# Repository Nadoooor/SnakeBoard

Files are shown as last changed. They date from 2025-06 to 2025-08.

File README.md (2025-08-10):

# SnakeBoard
It is a custom keycool84 size keyboard with dual oled screens and a rotary encoder.<br>
I made this project to improve my cad skills and pcb designing skills. Also, i need a good keyboard to write my homework with.<br>
The Onshape Doc: [DOC](https://cad.onshape.com/documents/902611e8b9feae564de8d9eb/w/ee044899b2f02c71afc87682/e/73f01ff6e236a97137583ab3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)<br>

## Photos:
### Schematic:


### PCB:


### 3D PCB:


### Final Case:


## BOM for SnakeBoard:
| Part name | link | price  |
|---|---|---|
| Key Switches x4 packs | [Link](https://www.amazon.eg/-/en/gp/product/B09QGQVQYD/ref=ox_sc_act_title_2?smid=A1ZVRGNO5AYLOV&psc=1) | $43.83 |
| keycaps | [Link](https://www.amazon.eg/-/en/Redragon-A101-Double-Shot-mechanical-keyboard/dp/B019OAQ6VI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) | $7.72  |
| Zener Diode BZX79-C5V1 (6.2 Volt) | [Link](https://mostelectronic.com/shop/components/diodes/zener-diode-bzx79-c5v1-6-2-volt/) | $0.92  |
| Solder Wire Singapore 25g (0.6mm -70/30) Singapore | [Link](https://mostelectronic.com/shop/tools/soldering-desoldering/solder-wire-singapore-25g-0-6mm-70-30-singapore/) | $1.53  |
| OLED LCD LED Display Module White (128X64) 0.96 inch) | [Link](https://mostelectronic.com/shop/displays-lcd-7-seg-led/lcd-modules-displays-lcd-7-seg-led/0-96%e2%80%b3-oled-4pin-lcd-led-display-module-i2c-iic-communicate-white-12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) | $6.25  |
| Rotary encoder | [Link](https://mostelectronic.com/shop/sensors/ec11-rotary-encoder-with-push-button-switch-5pin-15mm/) | $0.5  |
| Raspberry pi pico | [Link](https://mostelectronic.com/shop/arduino-development-boards/raspberry-pi/raspberry-pi-pico/) | $10 |
| Shift register |[Link](https://www.ram-e-shop.com/shop/74hc165-ic-74165-8-bit-parallel-in-serial-out-shift-register-6231) | $0.31  |
| Total JLCPCb with shipping|  | $30 |
| shipping for most electronics | | $3.06  |
| shipping for amazon eg | | $2 |
| 3D Printed case | | $36.10 |
| Total | | $141.59|

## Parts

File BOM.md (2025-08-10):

# BOM for SnakeBoard:
| Part name | link | price  |
|---|---|---|
| Key Switches x4 packs | [Link](https://www.amazon.eg/-/en/gp/product/B09QGQVQYD/ref=ox_sc_act_title_2?smid=A1ZVRGNO5AYLOV&psc=1) | $43.83 |
| keycaps | [Link](https://www.amazon.eg/-/en/Redragon-A101-Double-Shot-mechanical-keyboard/dp/B019OAQ6VI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) | $7.72  |
| Zener Diode BZX79-C5V1 (6.2 Volt) | [Link](https://mostelectronic.com/shop/components/diodes/zener-diode-bzx79-c5v1-6-2-volt/) | $0.92  |
| Solder Wire Singapore 25g (0.6mm -70/30) Singapore | [Link](https://mostelectronic.com/shop/tools/soldering-desoldering/solder-wire-singapore-25g-0-6mm-70-30-singapore/) | $1.53  |
| OLED LCD LED Display Module White (128X64) 0.96 inch) | [Link](https://mostelectronic.com/shop/displays-lcd-7-seg-led/lcd-modules-displays-lcd-7-seg-led/0-96%e2%80%b3-oled-4pin-lcd-led-display-module-i2c-iic-communicate-white-12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) | $6.25  |
| Rotary encoder | [Link](https://mostelectronic.com/shop/sensors/ec11-rotary-encoder-with-push-button-switch-5pin-15mm/) | $0.5  |
| Raspberry pi pico | [Link](https://mostelectronic.com/shop/arduino-development-boards/raspberry-pi/raspberry-pi-pico/) | $10 |
| Shift register |[Link](https://www.ram-e-shop.com/shop/74hc165-ic-74165-8-bit-parallel-in-serial-out-shift-register-6231) | $0.31  |
| Total JLCPCb with shipping|  | $30 |
| shipping for most electronics | | $3.06  |
| shipping for amazon eg | | $2 |
| 3D Printed case | | $36.10 |
| Total | | $141.59|

## Note:
JLCPCB total is with 20$ coupon:<br>

<br>
### Print legion shipping will be more then what i will pay for printing it in my country.

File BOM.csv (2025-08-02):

Part name | link | price
Key Switches x4 packs | https://www.amazon.eg/-/en/gp/product/B09QGQVQYD/ref=ox_sc_act_title_2?smid=A1ZVRGNO5AYLOV&psc=1 | $43.83
keycaps | https://www.amazon.eg/-/en/Redragon-A101-Double-Shot-mechanical-keyboard/dp/B019OAQ6VI | $7.72
Zener Diode BZX79-C5V1 (6.2 Volt) | https://mostelectronic.com/shop/components/diodes/zener-diode-bzx79-c5v1-6-2-volt/ | $0.92
Solder Wire Singapore 25g (0.6mm -70/30) Singapore | https://mostelectronic.com/shop/tools/soldering-desoldering/solder-wire-singapore-25g-0-6mm-70-30-singapore/ | $1.53
Soldering Iron Station Tips 5pcs | https://mostelectronic.com/shop/tools/soldering-desoldering/soldering-iron-station-tips-5pcs/ | $1.32
Joker Soldering Paste Flux for Multi-Purpose 50g | https://mostelectronic.com/shop/tools/soldering-desoldering/joker-soldering-paste-flux-for-multi-purpose-50g/ | $1.22
OLED LCD LED Display Module White (128X64) 0.96 inch) | https://mostelectronic.com/shop/displays-lcd-7-seg-led/lcd-modules-displays-lcd-7-seg-led/0-96%e2%80%b3-oled-4pin-lcd-led-display-module-i2c-iic-communicate-w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 | $6.25
Rotary encoder | https://mostelectronic.com/shop/sensors/ec11-rotary-encoder-with-push-button-switch-5pin-15mm/ | $0.5
Raspberry pi pico | https://mostelectronic.com/shop/arduino-development-boards/raspberry-pi/raspberry-pi-pico/ | $10
Shift register | https://www.ram-e-shop.com/shop/74hc165-ic-74165-8-bit-parallel-in-serial-out-shift-register-6231 | $0.31
Stablizers | https://ar.aliexpress.com/item/1005006010710197.html?mp=1 | $4
Total JLCPCb with shipping |  | $30
shipping for most electronics |  | $3.06
shipping for amazon eg |  | $2
3D Printed case |  | $36.10
Total |  | $148.1

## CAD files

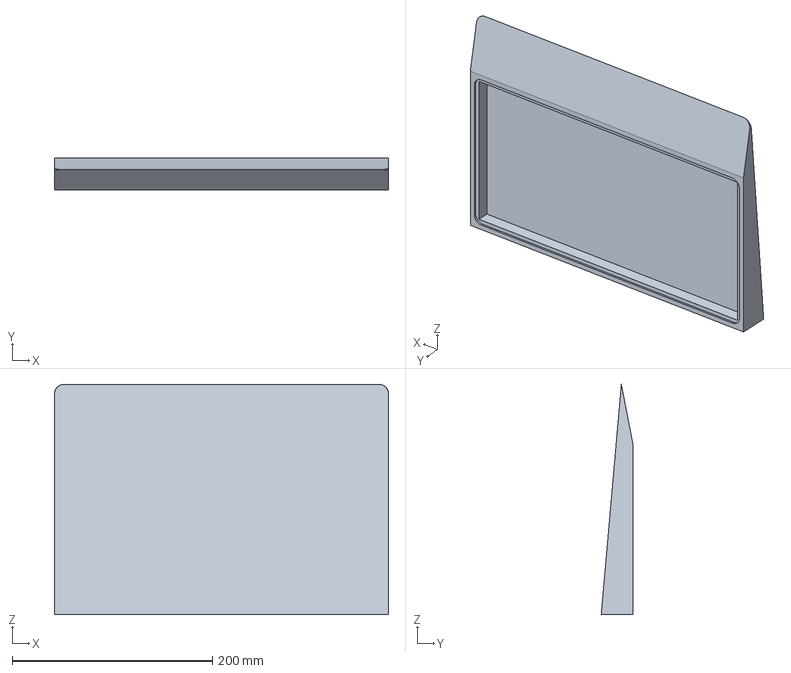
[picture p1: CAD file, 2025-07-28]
Production/Case/bottom.step
333.9 x 31.6 x 230.3 mm

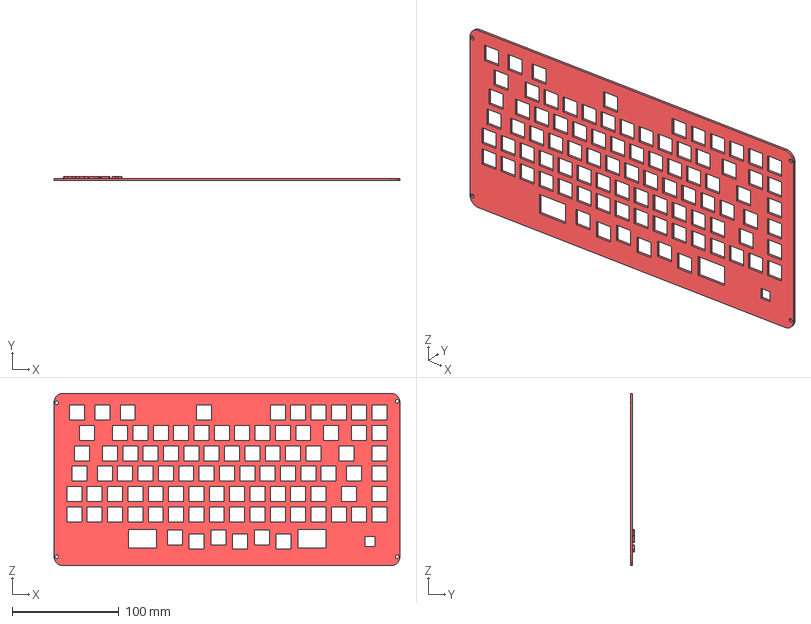
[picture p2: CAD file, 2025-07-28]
Production/Case/plate.step
323.9 x 4.00 x 161.4 mm

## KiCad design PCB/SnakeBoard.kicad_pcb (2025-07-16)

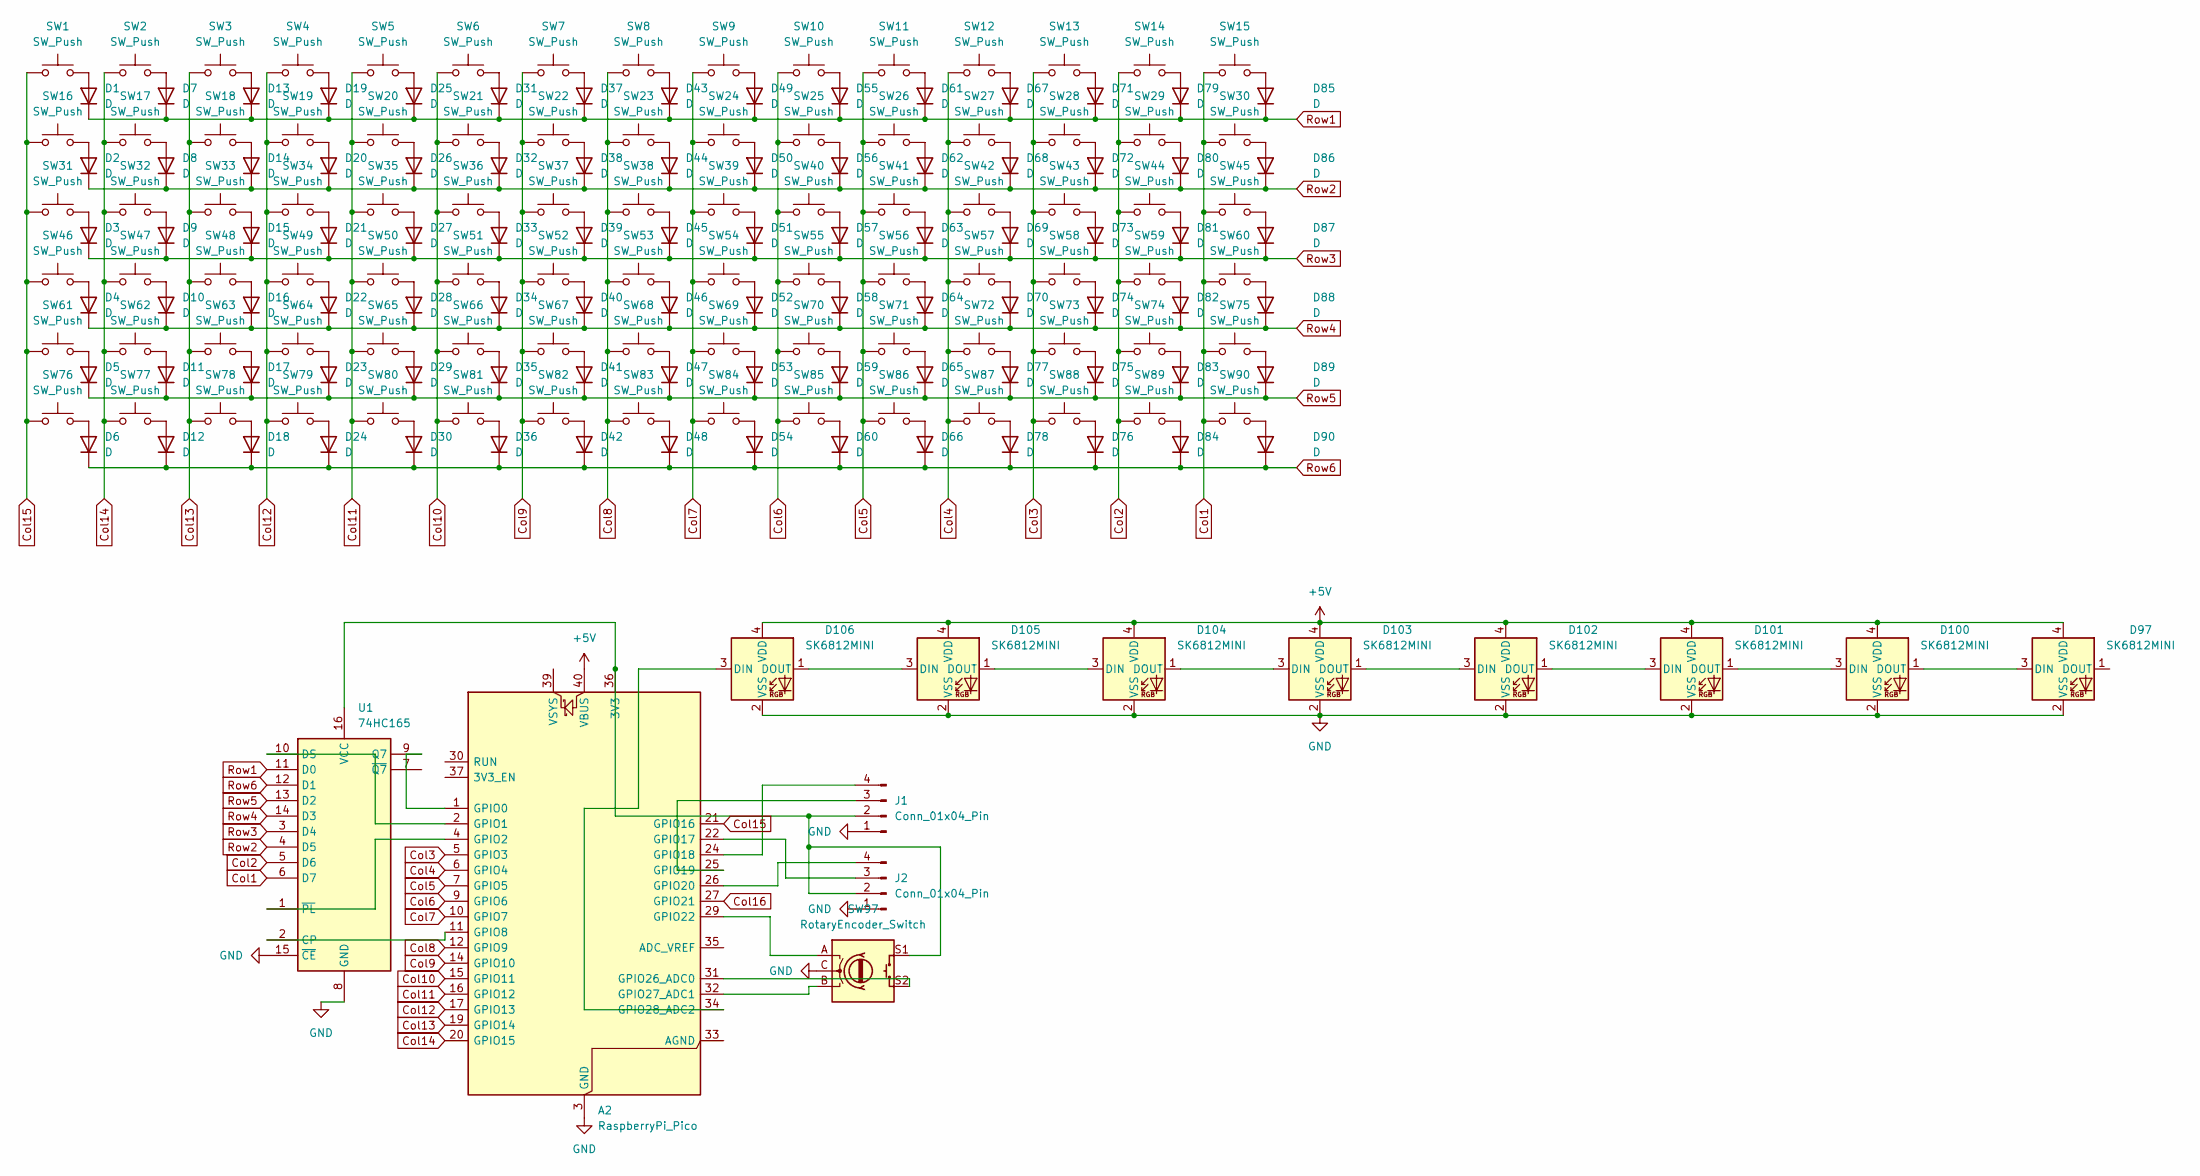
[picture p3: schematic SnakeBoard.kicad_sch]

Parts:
A2: RaspberryPi_Pico; RaspberryPi_Pico_Common_Unspecified
D1, D2, D3, D4, D5, D6, D7, D8, D9, D10, D11, D12, D13, D14, D15, D16, D17, D18, D19, D20, D21, D22, D23, D24, D25, D26, D27, D28, D29, D30, D31, D32, D33, D34, D35, D36, D37, D38, D39, D40, D41, D42, D43, D44, D45, D46, D47, D48, D49, D50, D51, D52, D53, D54, D55, D56, D57, D58, D59, D60, D61, D62, D63, D64, D65, D66, D67, D68, D69, D70, D71, D72, D73, D74, D75, D76, D77, D78, D79, D80, D81, D82, D83, D84, D85, D86, D87, D88, D89, D90: D; D_DO-35_SOD27_P7.62mm_Horizontal
D97, D100, D101, D102, D103, D104, D105, D106: SK6812MINI; LED_SK6812MINI_PLCC4_3.5x3.5mm_P1.75mm
J1, J2: Conn_01x04_Pin; SSD1306_0.96_Oled
SW1, SW2, SW3, SW4, SW5, SW6, SW7, SW8, SW9, SW10, SW11, SW12, SW13, SW14, SW15, SW16, SW17, SW18, SW19, SW20, SW21, SW22, SW23, SW24, SW25, SW26, SW27, SW28, SW29, SW30, SW31, SW32, SW33, SW34, SW35, SW36, SW37, SW38, SW39, SW40, SW41, SW42, SW43, SW44, SW45, SW46, SW47, SW48, SW49, SW50, SW51, SW52, SW53, SW54, SW55, SW56, SW57, SW58, SW59, SW60, SW61, SW62, SW63, SW64, SW65, SW66, SW67, SW68, SW69, SW70, SW71, SW72, SW73, SW74, SW75, SW76, SW77, SW78, SW79, SW80, SW81, SW82, SW83, SW84, SW85, SW86, SW87, SW88, SW89, SW90: SW_Push; SW_Cherry_MX_1.00u_PCB
SW97: RotaryEncoder_Switch; RotaryEncoder_Alps_EC12E-Switch_Vertical_H20mm
U1: 74HC165; DIP-16_W7.62mm

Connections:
+5V: A2.40 (VBUS), D97.4 (VDD), D100.4 (VDD), D101.4 (VDD), D102.4 (VDD), D103.4 (VDD), D104.4 (VDD), D105.4 (VDD), D106.4 (VDD)
Col1: SW15.1, SW30.1, SW45.1, SW60.1, SW75.1, SW90.1, U1.6 (D7)
Col2: SW14.1, SW29.1, SW44.1, SW59.1, SW74.1, SW89.1, U1.5 (D6)
Col3: A2.5 (GPIO3), SW13.1, SW28.1, SW43.1, SW58.1, SW73.1, SW88.1
Col4: A2.6 (GPIO4), SW12.1, SW27.1, SW42.1, SW57.1, SW72.1, SW87.1
Col5: A2.7 (GPIO5), SW11.1, SW26.1, SW41.1, SW56.1, SW71.1, SW86.1
Col6: A2.9 (GPIO6), SW10.1, SW25.1, SW40.1, SW55.1, SW70.1, SW85.1
Col7: A2.10 (GPIO7), SW9.1, SW24.1, SW39.1, SW54.1, SW69.1, SW84.1
Col8: A2.12 (GPIO9), SW8.1, SW23.1, SW38.1, SW53.1, SW68.1, SW83.1
Col9: A2.14 (GPIO10), SW7.1, SW22.1, SW37.1, SW52.1, SW67.1, SW82.1
Col10: A2.15 (GPIO11), SW6.1, SW21.1, SW36.1, SW51.1, SW66.1, SW81.1
Col11: A2.16 (GPIO12), SW5.1, SW20.1, SW35.1, SW50.1, SW65.1, SW80.1
Col12: A2.17 (GPIO13), SW4.1, SW19.1, SW34.1, SW49.1, SW64.1, SW79.1
Col13: A2.19 (GPIO14), SW3.1, SW18.1, SW33.1, SW48.1, SW63.1, SW78.1
Col14: A2.20 (GPIO15), SW2.1, SW17.1, SW32.1, SW47.1, SW62.1, SW77.1
Col15: A2.21 (GPIO16), SW1.1, SW16.1, SW31.1, SW46.1, SW61.1, SW76.1
Col16: A2.27 (GPIO21)
GND: A2.3 (GND), A2.8 (GND), A2.13 (GND), A2.18 (GND), A2.23 (GND), A2.28 (GND), A2.38 (GND), D97.2 (VSS), D100.2 (VSS), D101.2 (VSS), D102.2 (VSS), D103.2 (VSS), D104.2 (VSS), D105.2 (VSS), D106.2 (VSS), J1.1, J2.1, SW97.C, U1.8 (GND), U1.15 (~CE)
unnamed: A2.36 (3V3), J1.2, J2.2, SW97.S1, U1.16 (VCC)
unnamed: A2.1 (GPIO0), U1.9 (Q7)
unnamed: A2.2 (GPIO1), U1.10 (DS)
unnamed: A2.4 (GPIO2), U1.1 (~PL)
unnamed: A2.11 (GPIO8), U1.2 (CP)
unnamed: A2.22 (GPIO17), J2.3
unnamed: A2.24 (GPIO18), J1.4
unnamed: A2.25 (GPIO19), J1.3
unnamed: A2.26 (GPIO20), J2.4
unnamed: A2.29 (GPIO22), SW97.A
unnamed: A2.31 (GPIO26_ADC0), SW97.S2
unnamed: A2.32 (GPIO27_ADC1), SW97.B
unnamed: A2.34 (GPIO28_ADC2), D106.3 (DIN)
unnamed: D1.2 (A), SW1.2
unnamed: D2.2 (A), SW16.2
unnamed: D3.2 (A), SW31.2
unnamed: D4.2 (A), SW46.2
unnamed: D5.2 (A), SW61.2
unnamed: D6.2 (A), SW76.2
unnamed: D7.2 (A), SW2.2
unnamed: D8.2 (A), SW17.2
unnamed: D9.2 (A), SW32.2
unnamed: D10.2 (A), SW47.2
unnamed: D11.2 (A), SW62.2
unnamed: D12.2 (A), SW77.2
unnamed: D13.2 (A), SW3.2
unnamed: D14.2 (A), SW18.2
unnamed: D15.2 (A), SW33.2
unnamed: D16.2 (A), SW48.2
unnamed: D17.2 (A), SW63.2
unnamed: D18.2 (A), SW78.2
unnamed: D19.2 (A), SW4.2
unnamed: D20.2 (A), SW19.2
unnamed: D21.2 (A), SW34.2
unnamed: D22.2 (A), SW49.2
unnamed: D23.2 (A), SW64.2
unnamed: D24.2 (A), SW79.2
unnamed: D25.2 (A), SW5.2
unnamed: D26.2 (A), SW20.2
unnamed: D27.2 (A), SW35.2
unnamed: D28.2 (A), SW50.2
unnamed: D29.2 (A), SW65.2
unnamed: D30.2 (A), SW80.2
unnamed: D31.2 (A), SW6.2
unnamed: D32.2 (A), SW21.2
unnamed: D33.2 (A), SW36.2
unnamed: D34.2 (A), SW51.2
unnamed: D35.2 (A), SW66.2
unnamed: D36.2 (A), SW81.2
unnamed: D37.2 (A), SW7.2
unnamed: D38.2 (A), SW22.2
unnamed: D39.2 (A), SW37.2
unnamed: D40.2 (A), SW52.2
unnamed: D41.2 (A), SW67.2
unnamed: D42.2 (A), SW82.2
unnamed: D43.2 (A), SW8.2
unnamed: D44.2 (A), SW23.2
unnamed: D45.2 (A), SW38.2
unnamed: D46.2 (A), SW53.2
unnamed: D47.2 (A), SW68.2
unnamed: D48.2 (A), SW83.2
unnamed: D49.2 (A), SW9.2
unnamed: D50.2 (A), SW24.2
unnamed: D51.2 (A), SW39.2
unnamed: D52.2 (A), SW54.2
unnamed: D53.2 (A), SW69.2
unnamed: D54.2 (A), SW84.2
unnamed: D55.2 (A), SW10.2
unnamed: D56.2 (A), SW25.2
unnamed: D57.2 (A), SW40.2
unnamed: D58.2 (A), SW55.2
unnamed: D59.2 (A), SW70.2
unnamed: D60.2 (A), SW85.2
unnamed: D61.2 (A), SW11.2
unnamed: D62.2 (A), SW26.2
unnamed: D63.2 (A), SW41.2
unnamed: D64.2 (A), SW56.2
unnamed: D65.2 (A), SW71.2
unnamed: D66.2 (A), SW86.2
unnamed: D67.2 (A), SW12.2
unnamed: D68.2 (A), SW27.2
unnamed: D69.2 (A), SW42.2
unnamed: D70.2 (A), SW57.2
unnamed: D71.2 (A), SW13.2
unnamed: D72.2 (A), SW28.2
unnamed: D73.2 (A), SW43.2
unnamed: D74.2 (A), SW58.2
unnamed: D75.2 (A), SW73.2
unnamed: D76.2 (A), SW88.2
unnamed: D77.2 (A), SW72.2
unnamed: D78.2 (A), SW87.2
unnamed: D79.2 (A), SW14.2
unnamed: D80.2 (A), SW29.2
unnamed: D81.2 (A), SW44.2
unnamed: D82.2 (A), SW59.2
unnamed: D83.2 (A), SW74.2
unnamed: D84.2 (A), SW89.2
unnamed: D85.2 (A), SW15.2
unnamed: D86.2 (A), SW30.2
unnamed: D87.2 (A), SW45.2
unnamed: D88.2 (A), SW60.2
unnamed: D89.2 (A), SW75.2
unnamed: D90.2 (A), SW90.2
unnamed: D100.3 (DIN), D101.1 (DOUT)
unnamed: D97.3 (DIN), D100.1 (DOUT)
unnamed: D101.3 (DIN), D102.1 (DOUT)
unnamed: D102.3 (DIN), D103.1 (DOUT)
unnamed: D103.3 (DIN), D104.1 (DOUT)
unnamed: D104.3 (DIN), D105.1 (DOUT)
unnamed: D105.3 (DIN), D106.1 (DOUT)
Row1: D1.1 (K), D7.1 (K), D13.1 (K), D19.1 (K), D25.1 (K), D31.1 (K), D37.1 (K), D43.1 (K), D49.1 (K), D55.1 (K), D61.1 (K), D67.1 (K), D71.1 (K), D79.1 (K), D85.1 (K), U1.11 (D0)
Row2: D2.1 (K), D8.1 (K), D14.1 (K), D20.1 (K), D26.1 (K), D32.1 (K), D38.1 (K), D44.1 (K), D50.1 (K), D56.1 (K), D62.1 (K), D68.1 (K), D72.1 (K), D80.1 (K), D86.1 (K), U1.4 (D5)
Row3: D3.1 (K), D9.1 (K), D15.1 (K), D21.1 (K), D27.1 (K), D33.1 (K), D39.1 (K), D45.1 (K), D51.1 (K), D57.1 (K), D63.1 (K), D69.1 (K), D73.1 (K), D81.1 (K), D87.1 (K), U1.3 (D4)
Row4: D4.1 (K), D10.1 (K), D16.1 (K), D22.1 (K), D28.1 (K), D34.1 (K), D40.1 (K), D46.1 (K), D52.1 (K), D58.1 (K), D64.1 (K), D70.1 (K), D74.1 (K), D82.1 (K), D88.1 (K), U1.14 (D3)
Row5: D5.1 (K), D11.1 (K), D17.1 (K), D23.1 (K), D29.1 (K), D35.1 (K), D41.1 (K), D47.1 (K), D53.1 (K), D59.1 (K), D65.1 (K), D75.1 (K), D77.1 (K), D83.1 (K), D89.1 (K), U1.13 (D2)
Row6: D6.1 (K), D12.1 (K), D18.1 (K), D24.1 (K), D30.1 (K), D36.1 (K), D42.1 (K), D48.1 (K), D54.1 (K), D60.1 (K), D66.1 (K), D76.1 (K), D78.1 (K), D84.1 (K), D90.1 (K), U1.12 (D1)

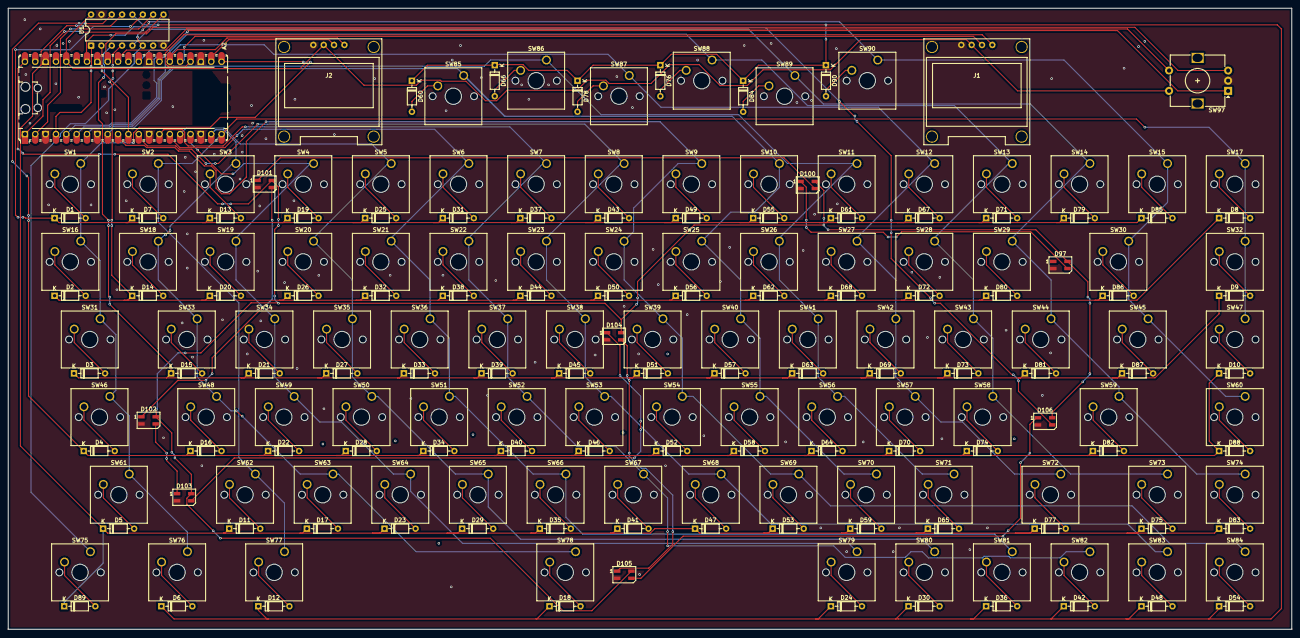
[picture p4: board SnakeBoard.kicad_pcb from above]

Board: 2 copper layers, 315.0 x 152.4 mm, 193 parts (0 on the bottom side), 133 nets.

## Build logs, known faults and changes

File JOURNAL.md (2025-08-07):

---
title: "SnakeBoard"
author: "Nader Sayed"
description: "A mechanical keyboard with cool screen and rotary encoders and more..."
created_at: "2025-06-12"
---
# Total hours spent on this project: 23 Hours.
# 30/6/2025
I have made the schematic and finished it. search for the key switches and where to buy them to add them to the BOM.
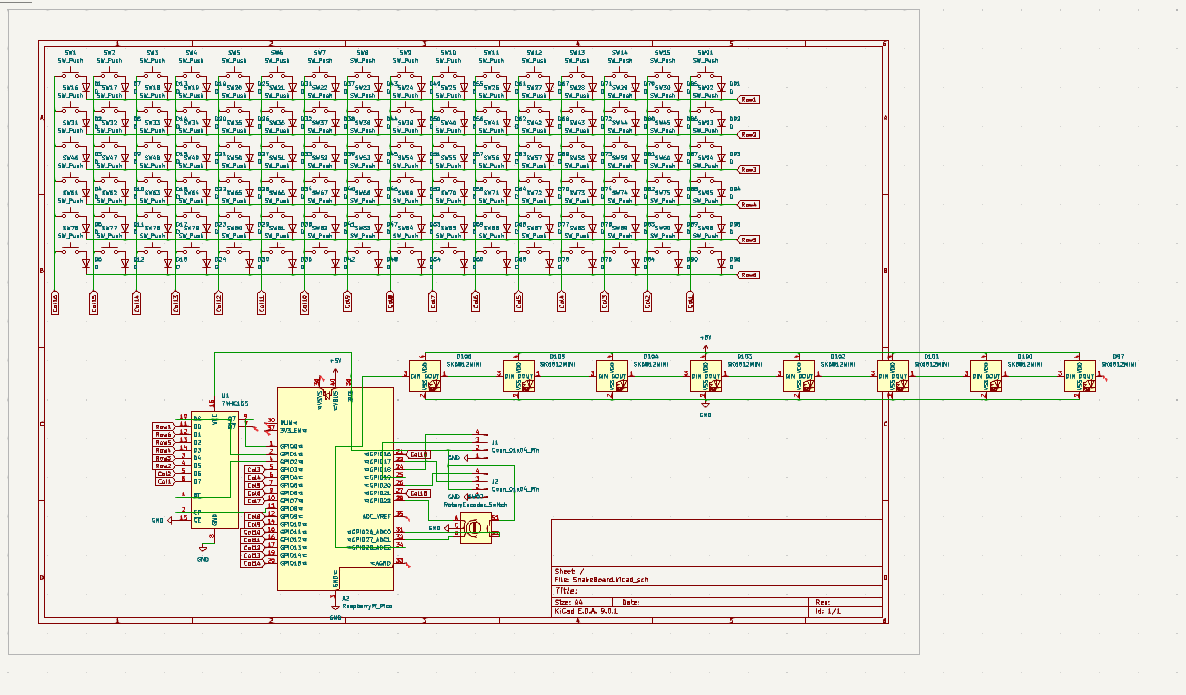
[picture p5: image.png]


worked for 2 hours, estimated, but with the hackatime sickness it shows 23m :(.

In the same day, but afternoon I added all the footprints. I got Scoopkeebs footprints to use, they were soooo helpful. and made the PCB and added the 3D designs and remains only the ROUTINGGGG ;).
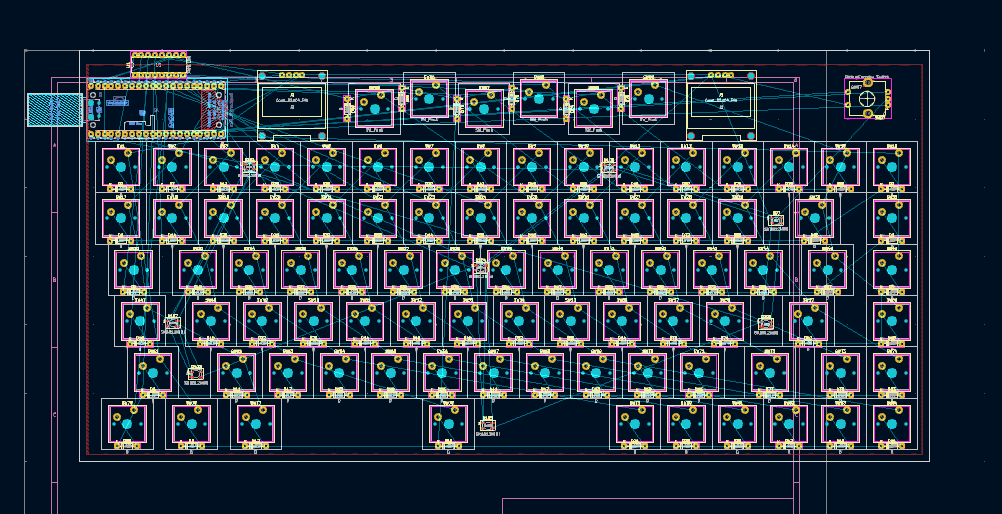
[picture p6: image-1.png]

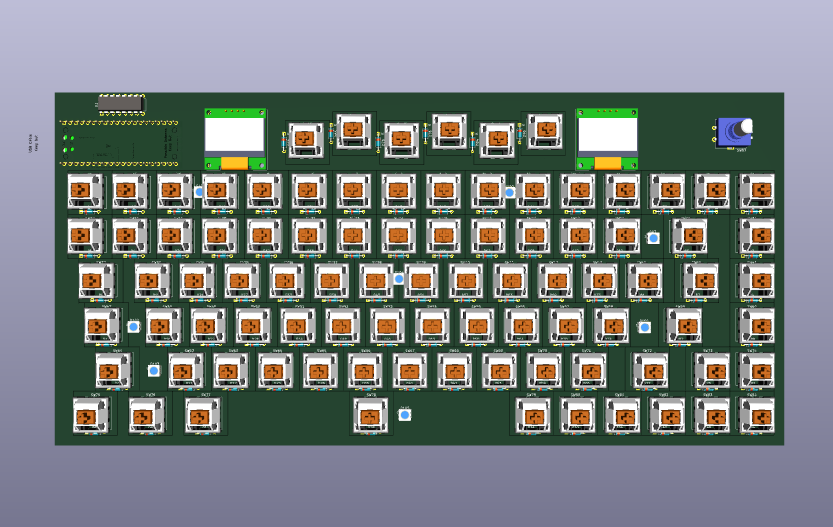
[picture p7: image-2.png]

## spent total: 5 hours
# 1/7/2025
Finished routing the PCB, and it was a nightmare routing everything needed a good space, but making the diodes routing from bottom and the switches from top was soo helpful and made routing more EZ. and making the fill method for the GND in all the components made it way easier and professional. Now it is all done. Only remains the Case now with Onshape.
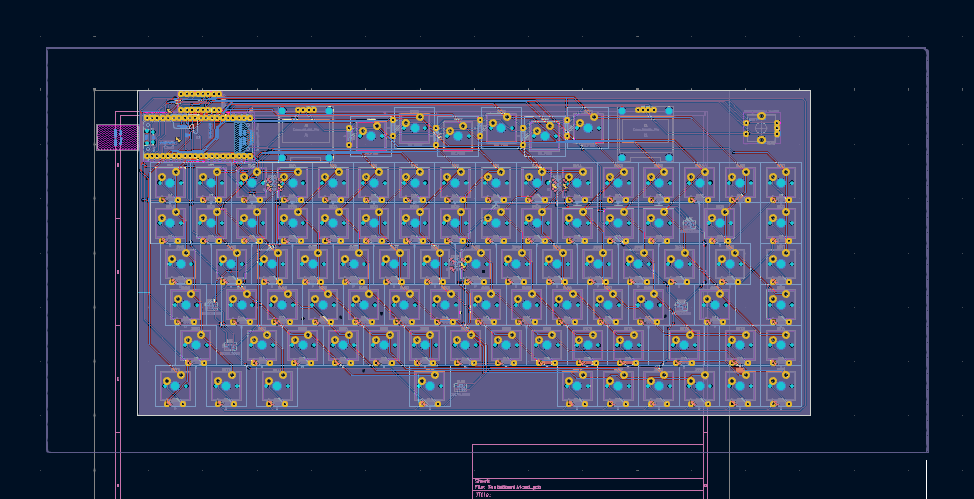
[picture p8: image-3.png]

## total hours: 2 hours
# 10/7/2025
worked on the case and finished the basics, it is like a brick now, it is kinda ugly. So, it needs more improvements. Just making a plate and a bottom without any polish is not enough. but for now i used [KLE](https://keyboard-layout-editor.com) to make the layout and export it to json so i can put it in [swillkb](http://builder.swillkb.com/) to get the dxf and import it into onshape so i can make the plate perfectly and i manually add the oled screen holes and the macros holes on Top. <br>
WhatsApp Image 2025-07-16 at 9 11 56 PM
## total hours: 5 hours
# 23/7/2025 it's been so long because I had a problem, but I'm back.
Worked on improving the case and enhancing its appearance and found that the red and black colors are so cool to use, also i made like a hand holder in the bottom of the keyboard. And it is all now done.
I loved my name so much, it is so cool on the case. I learned how to make an in-context part studio so I can edit my case while I see my keyswitches' location to add the holes.
250723_22h12m43s_screenshot
250723_21h27m36s_screenshot
The Onshape Doc: [DOC](https://cad.onshape.com/documents/902611e8b9feae564de8d9eb/w/ee044899b2f02c71afc87682/e/73f01ff6e236a97137583ab3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)<br>
## Total hours: 7 hours

# 25/7/2025
I got [kbfirmware](https://kbfirmware.com/) it uses QMK to build a hex file so I can put it in the Raspberry Pi Pico to make the keyboard work, but the keyboard layout in the PCB was different so I edited all the keys so they can be the same as the PCB <br>
Now I'm ready to submit.
## total hours: 1 hours

# 7/8/2025 
I changed the keyboard case to be more polished, so I added a skull and snakes on the case to be more related to my project name, snakeboard.<br>
I also made the USB hole because I forgot to add it. Rounding the edges was very important too, it is moooooore goood now with the rounded edges. I left the down edges so it can be more static on the table.<br>
Images:<br>




## Total hours: 3 hours.

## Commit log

2025-06-26 Test Commit
    [SnakeBoard.kicad_pcb, SnakeBoard.kicad_sch]
2025-06-27 add the switches
2025-06-29 add teh schematic changes
    [SnakeBoard.kicad_sch]
2025-06-30 Add the schematic
2025-06-30 Added the PCB remains the routing
    [SnakeBoard.kicad_pcb, SnakeBoard.kicad_sch]
2025-06-30 Finished the PCB and it is all done.
    [SnakeBoard.kicad_pcb]
